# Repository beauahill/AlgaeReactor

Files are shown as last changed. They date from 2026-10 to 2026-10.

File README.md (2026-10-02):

# Mini Chaeto Reactor (10 gal reef)

Two builds that share the same **lid**, **deck plate** and **LED tube**:

| | Option A – acrylic tube | Option B – fully printed |
|---|---|---|
| Body | purchased 3" OD x 1/8" wall clear acrylic tube, 190 mm long | one printed piece (wall + base), 210 mm tall |
| Printed parts | `base_acrylic`, `lid`, `deck_plate` | `printed_body`, `lid`, `deck_plate` |
| See chaeto? | yes | no (opaque) |
| Seal | O-ring at each tube end | O-ring at lid; body is one piece |

Both give a ~0.5 L chaeto chamber (69.85 mm ID x ~159 mm tall, minus the LED tube) – roughly 1-2 cups of loosely packed chaeto, which is about right for a 10 gal.

## How it works
Water enters a side barb at the bottom, fills a plenum, and rises through the **deck plate** (2.5 mm holes), tumbling the chaeto. It leaves through the **lid screen** (2 mm holes) into an upper plenum with a 45 deg roof (no supports; any air collects at the apex where the **vertical outlet barb** is). A 25 mm test tube stands in a socket ring on the deck plate and passes through a column in the lid, sealed with a 24 x 2 mm O-ring. The LED strip lives dry inside the test tube.

## Bill of materials
- Test tube, rimless borosilicate **25 x 200 mm** (the LED tube)
- LED strip, 8-10 mm wide, ~185 mm x 3 (one per face of `led_spine`) – 12/24 V, no need for waterproof; use a red/blue or full-spectrum "grow" ratio
- Gaskets: either buy O-rings or print them in TPU (`gasket.stl`, see below). O-rings: **64 x 2.5 mm** x2 (Option A) or x1 (Options B / B2) – tube ends; **24 x 2 mm** x1 – test tube. Nitrile or silicone.
- Options A / B: 3x M4 threaded rod, ~225 mm; 3x M4 hex nuts (trapped in the base), 3x M4 nut + washer (or wing nut) on top. Option B2 needs none of this.
- 2x hose, 1/2" (12 mm) ID, to a small pump (~100-300 L/h, throttled) and back to the tank/sump
- Option A only: acrylic tube 76.2 mm OD x 3.175 mm wall, cut to 190 mm (7.5"), ends square

## Print notes
- **PETG or ASA** (PLA will creep/soften near the LEDs and in a warm room). Not tested with food-contact claims; it's a reef pump loop, so use aquarium-safe filament and rinse well.
- 0.2 mm layers, **>= 4 perimeters, 100% infill or 5+ top/bottom layers** so walls are watertight. Printed body wall is 3.2 mm (8 perimeters at 0.4).
- Orientations (all print as exported, no supports except noted):
  - `lid`: as modelled (plug down, screen on the bed, barb pointing up) – roof is 45 deg
  - `base_acrylic` / `printed_body`: flange on bed; the **horizontal inlet barb** may want a little support under it
  - `deck_plate`: flat, socket ring up
  - `thread_ring`: exported lip-down on the bed (thread axis vertical). `printed_body_threaded` prints upright like `printed_body`; the thread flanks are 60 deg so they need no supports
  - `led_spine`: upright, or lying down
- Printed body is **210 mm tall** – needs a >= 210 mm Z build volume. If yours is shorter, reduce `tube_len` in `params.scad` (and use a shorter test tube), or use Option A.

## Assembly
1. Seat the O-rings in the plug grooves (Option A base, lid plug).
2. Option A: push the acrylic tube over the base plug and lid plug. Option B: drop in nothing – the lid plug goes straight into the printed body.
3. Drop the deck plate onto the plug rim / printed ledge (it just rests there so you can lift it out for cleaning).
4. Fit the 24 x 2 mm O-ring in the lid column groove, then push the test tube (LED already inside) down through the lid until it sits in the deck-plate socket. It protrudes ~11 mm above the lid for the wires.
5. Thread the M4 rods through the lid and base, nuts in the base pockets, and snug the top nuts evenly. Rods only keep the lid from popping under back-pressure; do not crank them.
6. Hose: pump -> bottom barb, top barb -> back to the display or sump. Run it, bleed air by tilting, then add chaeto and adjust flow until it just tumbles.

## TPU gaskets (optional)
`gasket.stl` is one plate with two 64 mm-ID tube gaskets (Option A needs both, Options B/B2 need one) and one 24 mm-ID test-tube gasket. They have the same ID and section size as the O-rings, so they sit in the same grooves. The section is a rounded square rather than round, because a round ring prints poorly flat.

- Filament: **95A TPU**, 0.2 mm layers (0.12 if you want a smoother seal face), **100% infill**, 20-30 mm/s, no supports, little or no retraction. A direct-drive extruder is much easier; on a Bowden setup go slower.
- Check them: they should be springy and the layers fused. Any gaps or stringing on the sealing faces will leak, so trim strings and reprint a gasket that looks porous.
- A thin smear of silicone grease (the aquarium or food-safe kind) fills the layer lines and makes them slide on without rolling or twisting. Do not use petroleum grease.
- **Not tested for sealing.** Printed TPU is not as reliable as a moulded O-ring. If a printed one weeps, swap in a real O-ring; nothing else in the design changes. Print one set and leak-test the lid before trusting it.
- The test-tube gasket stretches about 4% over the tube; if it feels too stiff to slide, increase its ID by 0.5 mm in `gasket.scad`.

## Option B2: threaded lid
`printed_body_threaded` has a 4 mm-pitch, 2 mm-deep right-hand thread on the top 16 mm (4 turns). `thread_ring` screws over it and its lip clamps down on the flange of `lid_threaded`, so the lid itself never rotates and the outlet barb stays where you aimed it. The ring clears the barb (ring lip is 34 mm radius, barb reaches 32.8 mm), so **fit the ring before pushing hoses onto the barbs**.

Assembly is the same as above except step 5: drop the lid on, spin the ring down by hand until the lip seats, snug (hand tight is enough; the O-ring does the sealing). Thread clearance is `thread_clr` (0.3 mm per side); if the ring is tight or sloppy on your printer, adjust it and re-export `thread_ring` only. Pitch, depth and length are in `params.scad`.

Checked in CAD: the ring clears the body thread and the lid, and the lip bears on the full flange face. Not yet test-printed. Print the ring alone first and screw it onto the body's thread section (print just the top of `printed_body_threaded` by cropping in your slicer) before committing to the full 210 mm print.

## Things to check before you print
- **Measure your acrylic's actual ID** and set `tube_wall`/`tube_od` in `openscad/params.scad`. Extruded tube varies by a few tenths. The O-ring grooves are derived from it for ~15% squeeze.
- This design has **not been printed or leak-tested**. Print the lid first (smallest, most complex) and test-fit the tube and O-rings before committing to the tall body.
- Buoyancy of the empty test tube is roughly cancelled by glass + LED weight; the O-ring friction should hold it. If yours floats up, add a small weight inside.
- Keep LED power low (a few watts) – the strips are in air inside glass and heat is shed into the water through the tube.

## Files
- `openscad/params.scad` – every dimension you may want to change
- `openscad/*.scad` – one file per part, plus `assembly_acrylic.scad` / `assembly_printed.scad` / `assembly_threaded.scad` for viewing
- `stl/` – pre-exported STLs; regenerate with `make` (needs OpenSCAD)

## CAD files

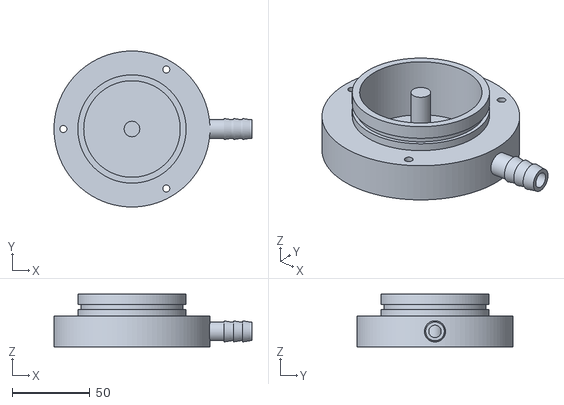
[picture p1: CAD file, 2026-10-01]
stl/base_acrylic.stl
127.2 x 100.2 x 34.0

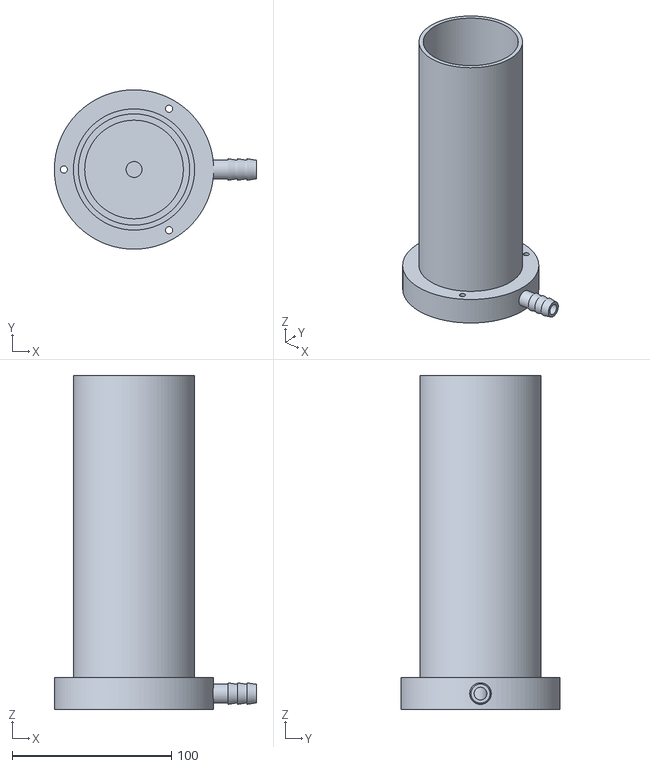
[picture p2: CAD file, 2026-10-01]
stl/printed_body.stl
127.2 x 100.2 x 210.0

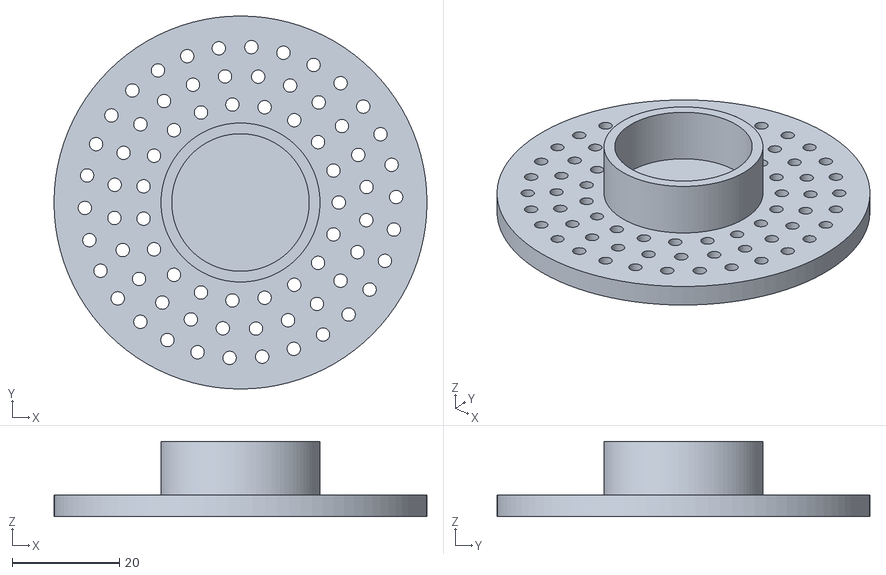
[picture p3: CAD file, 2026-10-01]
stl/deck_plate.stl
69.5 x 69.5 x 14.0

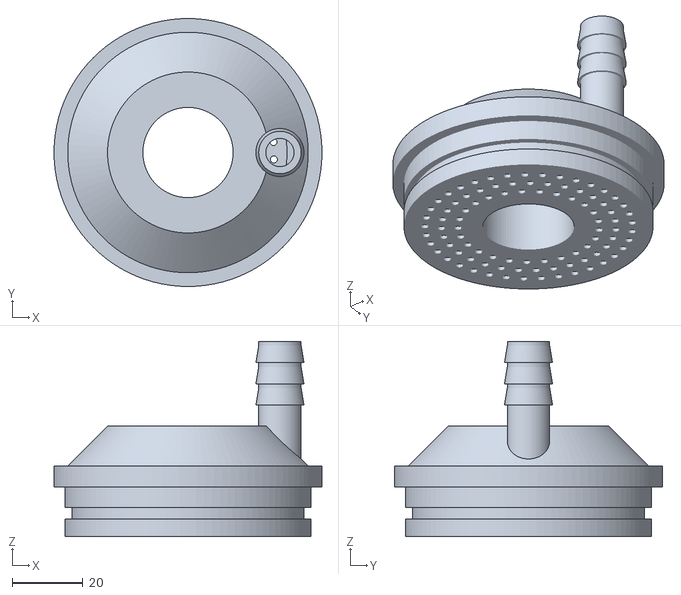
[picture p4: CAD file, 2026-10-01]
stl/lid_threaded.stl
75.8 x 75.8 x 55.2

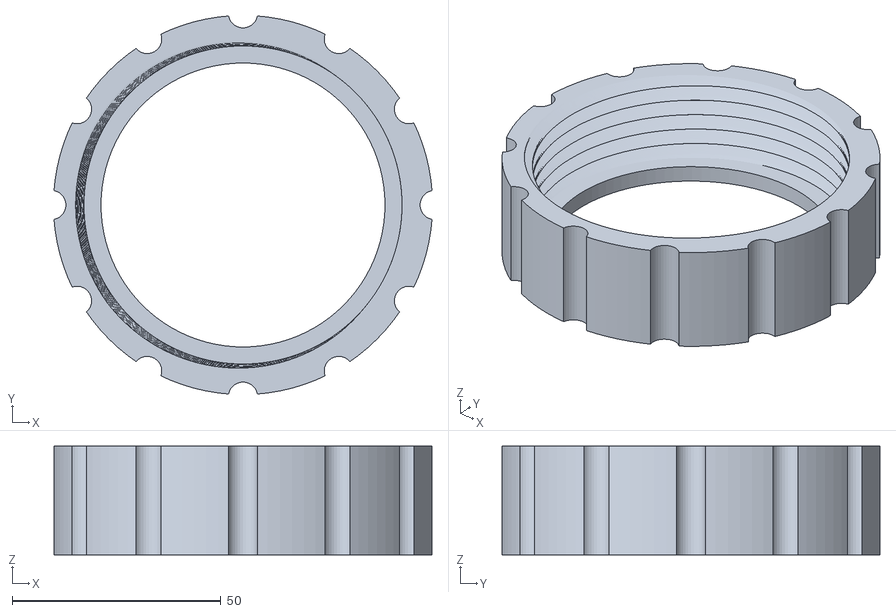
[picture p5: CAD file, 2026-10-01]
stl/thread_ring.stl
90.5 x 90.5 x 26.0

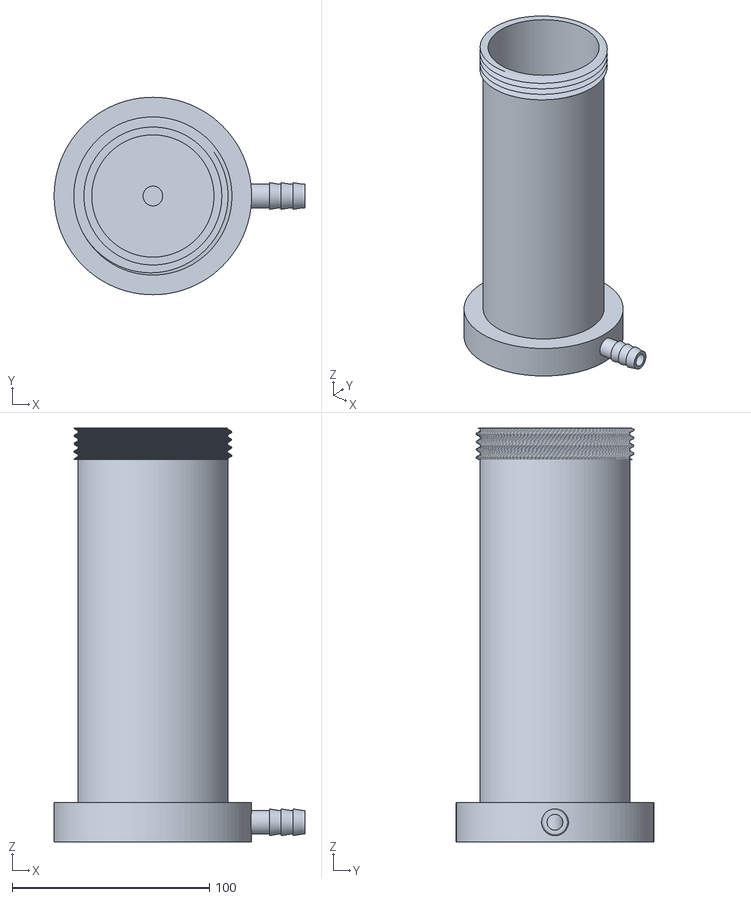
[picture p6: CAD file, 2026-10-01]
stl/printed_body_threaded.stl
127.2 x 100.2 x 210.0

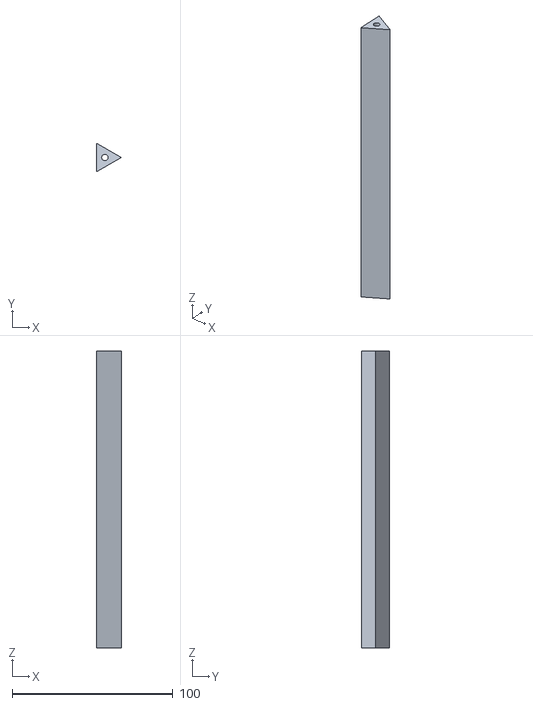
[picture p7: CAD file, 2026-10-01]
stl/led_spine.stl
15.3 x 17.7 x 185.0

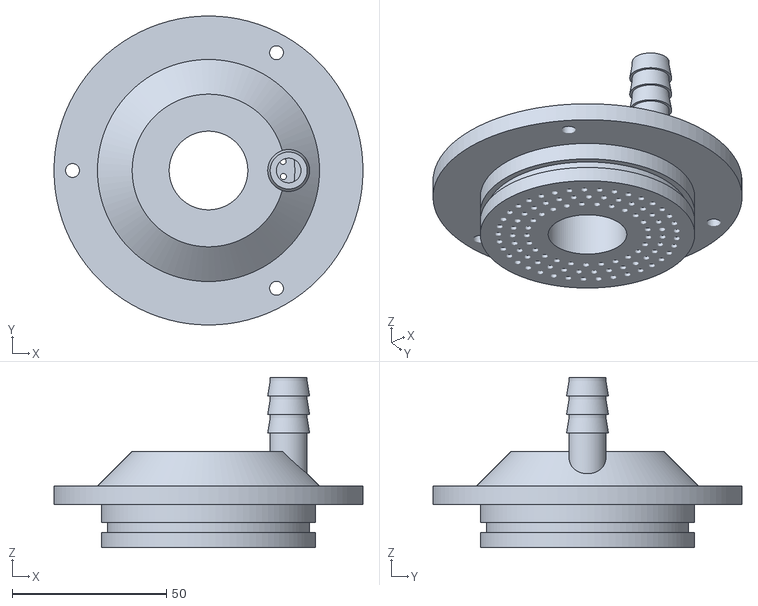
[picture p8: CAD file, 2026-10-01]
stl/lid.stl
100.2 x 100.2 x 55.2

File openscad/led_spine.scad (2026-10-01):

// Triangular core for LED strip: one strip per face, slides into the test tube.
include <params.scad>

spine_len   = tt_len - 15;
spine_r     = 10.2;     // vertex radius (test tube ID is ~22)
module led_spine() {
    difference() {
        linear_extrude(spine_len) circle(r = spine_r, $fn = 3);
        translate([0, 0, -1]) cylinder(d = 4, h = spine_len + 2, $fn = 24);
    }
}
led_spine();

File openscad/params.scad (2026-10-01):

// Chaeto reactor - shared parameters (all dimensions in mm)
// Edit the "purchased parts" block to match what you actually buy,
// then re-export the STLs (see ../Makefile).

$fn = 96;

// ---------- purchased parts ----------
tube_od    = 76.2;     // acrylic tube OD (3")
tube_wall  = 3.175;    // acrylic tube wall (1/8"). MEASURE your tube's real ID.
tube_len   = 190;      // acrylic tube cut length (also the printed body height)
tt_od      = 25;       // test tube OD (rimless 25 x 200 borosilicate)
tt_len     = 200;      // test tube length
hose_id    = 12;       // tubing ID the barbs are sized for (1/2")
rod_d      = 4;        // M4 tie rods

// ---------- derived ----------
tube_id    = tube_od - 2*tube_wall;
plug_od    = tube_id - 0.3;           // slip fit inside the tube
plug_h     = 14;
bore_d     = 62;                      // plenum / outlet cavity diameter
bore_r     = bore_d/2;

// tube-end O-ring (round cord, ID x CS)
oring_cs        = 2.5;
oring_id        = 64;                 // 64 x 2.5 mm
groove_root_r   = tube_id/2 - 0.85*oring_cs;   // ~15% squeeze against the tube ID
groove_w        = oring_cs + 0.7;

// test tube O-ring in the lid column
tt_oring_cs     = 2;                  // 24 x 2 mm
tt_bore_r       = (tt_od + 0.5)/2;
tt_groove_root_r= tt_od/2 + 0.85*tt_oring_cs;
tt_groove_w     = tt_oring_cs + 0.6;

// flanges / tie rods
flange_r   = tube_od/2 + 12;
rod_r      = tube_od/2 + 6;
rod_hole_d = rod_d + 0.5;
rod_angles = [60, 180, 300];
nut_af     = 7;                       // M4 nut across flats
nut_t      = 3.2;

// base
base_h     = 20;                      // flange thickness below tube seat
floor_t    = 3;
deck_t     = 4;
deck_od    = tube_id - 0.4;

// lid
screen_t   = 3;
flange_t   = 6;
col_r      = tt_bore_r + 4;
roof_h     = bore_r - col_r;          // 45 deg roof, prints without supports
top_z      = roof_h + 3;
lid_barb_x = 26;

// barbs / holes
barb_len   = 32;
barb_bore  = 8;
hole_d     = 2.5;                     // deck holes (flow in)
screen_hole_d = 2.0;                  // lid screen holes (flow out)

printed_bore_tol = 0.1;               // extra clearance on the printed body ID

// ---------- threaded retaining ring (printed body, no tie rods) ----------
thread_pitch = 4;
thread_depth = 2;
thread_len   = 16;          // engaged length (4 turns)
thread_clr   = 0.3;         // radial clearance on the ring's internal thread
ring_lip     = 4;           // thickness of the ring's top lip
ring_lip_r   = 34;          // lip inner radius (clears the outlet barb, bears on the lid flange)
ring_r       = tube_od/2 + thread_depth + thread_clr + 5;
lid_th_flange_r = tube_od/2 - 0.2;   // lid flange must pass inside the ring's thread

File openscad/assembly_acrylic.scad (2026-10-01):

use <base_acrylic.scad>
use <deck_plate.scad>
use <lid.scad>
include <params.scad>

module assembly_acrylic(cut = true) {
    difference() {
        union() {
            color("gray") base_acrylic();
            color("white") translate([0, 0, plug_h]) deck_plate();
            color("lightblue", 0.35) difference() {
                cylinder(d = tube_od, h = tube_len);
                translate([0, 0, -1]) cylinder(d = tube_id, h = tube_len + 2);
            }
            color("gray") translate([0, 0, tube_len]) lid();
            color("gold") translate([0, 0, plug_h + deck_t]) cylinder(d = tt_od, h = tt_len);
        }
        if (cut) translate([0, -200, -50]) cube([200, 200, 400]);
    }
}
assembly_acrylic();

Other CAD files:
openscad/assembly_printed.scad
openscad/assembly_threaded.scad
openscad/base_acrylic.scad
openscad/deck_plate.scad
openscad/gasket.scad
openscad/lib.scad
openscad/lid.scad
openscad/lid_threaded.scad
openscad/printed_body.scad
openscad/printed_body_threaded.scad
openscad/thread_ring.scad

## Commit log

2026-10-01 Add parametric chaeto reactor: acrylic-tube and fully printed variants
    Shared lid, deck plate and LED spine; OpenSCAD sources, STLs, Makefile and build notes.
    Claude-Session: https://claude.ai/code/session_01VFGWD2U4sfb7AwsgherdxW
    [assembly_acrylic.scad, assembly_printed.scad, base_acrylic.scad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]
2026-10-01 Add threaded retaining-ring option for the printed body
    printed_body_threaded has a 4 mm pitch external thread; thread_ring clamps
    lid_threaded so no tie rods are needed. Lid barb stub now starts on the flange
    top (fully supported). Updated Makefile and README.
    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
    [assembly_threaded.scad, base_acrylic.stl, deck_plate.stl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]
2026-10-02 Add printable TPU gasket plate
    Rounded-square section rings matching the 64x2.5 and 24x2 O-ring grooves;
    README notes on TPU settings and caveats.
    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
    [gasket.scad]
2026-10-12 Fix threaded lid fit; open outlet bore; add thread test coupon
    Threads were built with 24 slices/turn, so the helical surface sagged ~0.34 mm,
    more than the 0.3 mm clearance. Now 72 slices/turn with 0.5 mm radial and
    0.3 mm per-side axial clearance, plus a lead-in chamfer on the ring and a
    narrower lid flange. Outlet bore now starts inside the plenum. Added
    thread_test.stl coupon and fit-test notes.
    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
2026-10-20 Replace threaded lid with bayonet ring; add two-piece printed tube
    - Bayonet ring (3 lugs, 60 deg turn to a stop, ~1 mm clearances) replaces the
    screw thread, which was too tight to start and cross-threaded. CAD-checked:
    inserts, turns to the stop, locks with 0.8 mm play, cannot lift when locked.
    - printed_tube + base_sealed: tube has no wall/base junction (where the
    one-piece body leaked); plug O-ring moved low; sealant moat around the
    tube's outer corner.
    - Plenum floor 3 -> 5 mm with a chamfered corner (all bases).
    - Removed thread code, parts and STLs; README rewritten.
    Claude-Session: https://claude.ai/code/session_01VFG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
2026-10-20 Cam-lock ring: spiral ramp pulls the lid down onto a flat gasket
    Lug undersides now spiral (1.5 mm over 40 deg, self-locking) so turning the
    ring wedges it down and compresses a 2.0->1.4 mm flat lid gasket. CAD-checked
    along the full turn: free travel, wedge engagement, stop wall, lid clearance.
    Fixed the lug polyhedron so it takes part in booleans. Added flat lid gasket
    to gasket.stl; coupon and README updated.
    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
2026-10-20 Add Option D: cam-lock at both ends (printed_tube_v2 + base_camlock)
    Tube gets a mirrored set of lugs at the bottom; the base grows a collar with
    three inward 45-deg tabs. Twisting the tube clockwise ~70 deg pulls it down
    onto a flat gasket, same ramp and squeeze as the lid ring, no silicone.
    Both locks turn the same way. Plug O-ring groove raised above the tube's
    bore chamfer on this base (base_acrylic gains a groove_z parameter, default
    unchanged). New fit coupons and a two-gasket TPU plate; existing Option B
    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
